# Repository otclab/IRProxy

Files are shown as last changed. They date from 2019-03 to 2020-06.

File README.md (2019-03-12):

# IRProxy

### Descripción del Proyecto

El proyecto surge de la necesidad de enviar señales de mando infrarrojas al decodificador  de cable, de manera de controlar su operación en forma remota desde donde no es posible  utilizar su propio control remoto infrarrojo.

La solución desarrollada es utilizar el conjunto _ESP8266_ y un microcontrolador <sup>(*1)</sup> de  manera obtener la capacidad de enviar los mandos desde una red inalámbrica (y por ende _LAN_ e  Internet inclusive), los cuales serían recibidos por el módulo _ESP8266_ y enviados por  medio del su puerto _SPI_ al microcontrolador, el cual se encargaría de generar la señal  infrarroja.

El microcontrolador se incluye porque en general el módulo _ESP8266_, no tiene la capacidad para generar un patrón infrarrojo arbitrario <sup>(*2)</sup> y porque la confiabilidad del microcontrolador es muy superior a la del módulo _ESP8266_ en cualquiera de los tres lenguajes que  se  usaron (_LUA_, _Arduino_/_++C_, y _(Micro)Python_), encargándose de cebar el sistema en caso  se pierda la comunicación por cualquier motivo.  

El protocolo de comunicación elegido es el **_MQTT_**, en razón que su soporte es mas estable y simple (contrario del _COAP_ o _HTTP_) en _NodeMCU_ <sup>(*3)</sup>. 

Por otro lado como frente _GUI_  en la _PC_ se  utiliza _Python_ con soporte de la librería _Kivy_, con la cual también se tiene mejor control  sobre el tamaño de la ventana de la aplicación y es menos exigente en cuanto recursos con  respecto a un navegador, con el agregado que facilita la compilación tanto para _Windows_ como  para _Android_ de manera de obtener aplicaciones para ambos SO.

La desventaja al utilizar el protocolo _MQTT_, es que debe utilizarse un servidor intermediario  (_Broker_), al contrario que en _Android_, por el lado de la _PC_ es un problema menor, para la  cual es fácil montar un servidor, sin embargo dado que el servidor _MQTT_ puede montarse en el  servidor _NAS_ como un servicio auxiliar que puede aprovecharse para otras aplicaciones _IoT_.

Con el fin de no restringir el proyecto a su objetivo inicial y también poder usarlo aún  es sus primeras etapas de desarrollo (con solo la captura de los patrones correspondientes a  las teclas mas frecuentes) sin realizar mayores cambios al adicionar nuevos patrones para  el mismo decodificador u otros equipos, se propone implementar el código del generador en  forma genérica, de manera que la estructura de tiempos del patrón es recibida cada vez  que deba emitirse.

 El libreto de _IPython_ _"Decodificacion de las Señales Infrarrojas del Control Remoto del  "Decodificador de Movistar.ipynb"_ se encarga de procesar la captura de las señales  infrarrojas realizadas con el osciloscopio _Rigol 1052E_, verifica la rectitud de la captura  y genera los archivos _XML_ de especificación de los patrones correspondientes, los  cuales pueden ser usados por la aplicación en _Python_ para la _PC_.

### Etapa Final 
 El diseño del equipo final incluye una fuente _DC/DC_ para compartir la alimentación del  decodificador, la cual proviene de un adaptador de _12VDC_, por lo que se incluye un  convertidor _DC/DC híbrido_ el cual consta de pre-regulador reductor conmutado, operando en lazo abierto seguido de un regulador lineal de 3.3V.  El microcontrolador auxiliar también se genera la señal de excitación del pre-regulador.
 
##### Notas
 
 >- <sup>(\*1)</sup>  Para la pruebas de concepto se utilizo el PIC16F1619, un sub-siguiente periodo de prueba se realizo con el PIC16F18313. En la etapa final para trabajo constante se utiliza también el PIC16F18313.
 >- <sup>(\*2)</sup>  La versión actual del SDK del ESP8266 tiene soporte para generación de señales infrarrojas aunque para un conjunto de formatos restringido, al momento no incluye el de Samsung.
 >- <sup>(\*3)</sup>  El módulo NodeMCU fue utilizado para las pruebas iniciales, programado en Lua resulto bastante inestable, en su lugar se utilizo para el periodo de prueba la versión de Arduino para el ESP8266, el cual fue bastante estable y requirió su reinicio pocas veces. Sin embargo después de la actualización del servidor NAS (a FreeNAS 11.0) perdió la capacidad de conectarse, por lo que se decidió utilizar Micropython como lenguaje de operación para el módulo.

### Patrón de Señales
  
Para conservar la capacidad de generar un patrón cualquiera su especificación se trasmite cada vez que deba generarse, ellas incluyen la frecuencia de la portadora, su ciclo de trabajo, seguido de la secuencia de tiempos de generación y pausa de los que consta.

El formato depende del medio donde se ejecuta el interprete _PC_, _ESP8266_ o _Microcontrolador_, para la aplicación de escritorio _IRProxy_PC.py_ se utiliza el formato _XML_, la especificación es embebida en la etiqueta **_IR_CODE_**, la cual contiene las etiquetas **_SOURCE_**, **_ID_**, **_CARRIER_**, y **_PATTERN_**.

La etiquetas **_SOURCE_** e **_ID_** sirven para identificar el equipo cuyas señales de control remoto infrarrojas y la tecla o función que emulan respectivamente.

<La etiqueta **_CARRIER_** incluye dos sub-etiquetas **_PERIOD_** y **_DUTY_CYCLE_**, en las que se definen los valores del periodo y ciclo de trabajo de la portadora, la unidad utilizada para estos se define por el atributo **_unit_** definido en la etiqueta **_CARRIER_**. Por conveniencia define la resolución del generador / temporizador utilizado para generarla (
<a href="https://www.codecogs.com/eqnedit.php?latex=\dpi{100}&space;\tiny&space;\frac{1}{32\,&space;MHZ}" target="_blank">\tiny \frac{1}{32\, MHZ}</a>
 para el PIC16F18313).

Dentro la etiqueta **_PATTERN_** se define la secuencia (_type="array"_) de pulsos, mediante la sub-etiquetas **_PULSE_**, las cuales a su vez constan de las etiquetas **_HIGH_** y **_LOW_**, que define los intervalos de activación y pausa de la portadora. Las unidades utilizadas se definen en el  atributo **_unit_**, como opción su valor puede ser _"CARRIER_PERIOD"_ implicando que las unidades  utilizadas para definir estos intervalos es el periodo de la portadora.

El formato para el envío del patrón hacia el módulo _ESP8266_, es una cadena de caracteres formada por la representación hexadecimal, de la secuencia de bytes que representan en forma consecutiva la _versión_, _número de pulsos_ el _periodo de la portadora_, su _ciclo de trabajo_, seguidos de los periodos de _activación_ y _pausa_ de cada pulso del patrón. 
En este caso no se trasmite la identificación del equipo y función a la que pertenece el patrón, pero se incluye la _versión del protocolo_, al momento solo existe la versión _1_ que es la descrita. Los valores de _127_  y _126_ se reservan para comunicación particular entre el módulo _ESP8266_ y el _microcontrolador_.

La secuencia de bytes de cada valor es la correspondiente a la codificación _VLQ_ (_Variable Length Quantity_), que utiliza el valor del bit de mayor peso de cada byte para indicar si es el último, es decir si la representación en base $128$ del valor es $A_n ...  A_1 A_0$, la secuencia utilizada es <span lang="latex">(A_0+128), (A_1+128), ... (A_n + 0)</span>. 

Nótese que los valores de los tiempos deben estar especificados en la unidad de tiempo utilizada por el microcontrolador.

Finalmente, el formato de envío al microcontrolador es la secuencia de bytes antes descrita ( no su representación hexadecimal).  Los valores reservados para la versión son utilizados para :
>- _0xFF_ : Informar que la comunicación es correcta (_keepalive_).
>- _0xFE_ : Solicitud de cebado del sistema (_reset_).

####  Limitaciones del Patrón de Señales
Desde el punto de vista de la arquitectura de la especificación y su serialización, no existe limitación, sin embargo la implementación de la generación en el _microcontrolador_ impone algunas :
  >- El campo del número de pulsos esta limitado a 255. En la practica el número de pulsos esta limitado por el almacenamiento reservado al patrón, en la versión actual 46 bytes.
  >- Los periodos de tiempo se limitan a 65535 de las unidades respectivas.

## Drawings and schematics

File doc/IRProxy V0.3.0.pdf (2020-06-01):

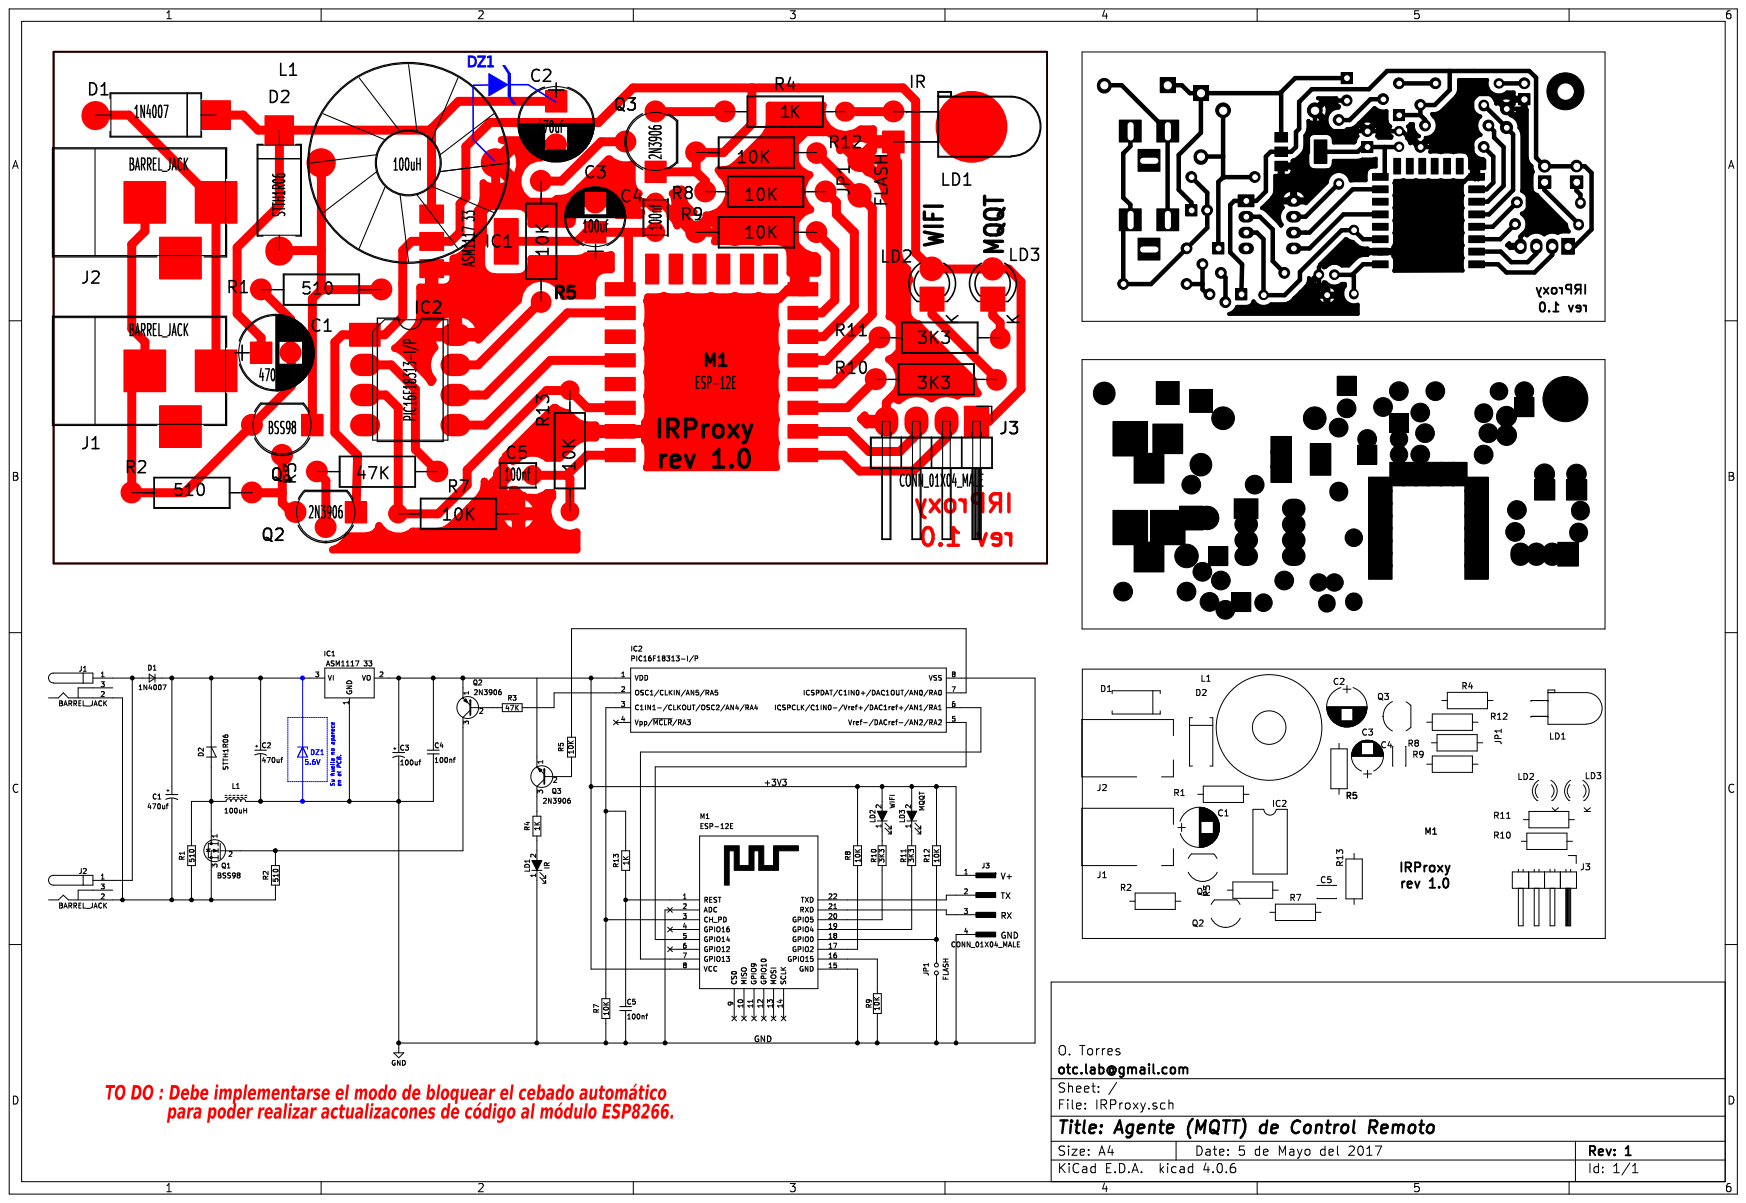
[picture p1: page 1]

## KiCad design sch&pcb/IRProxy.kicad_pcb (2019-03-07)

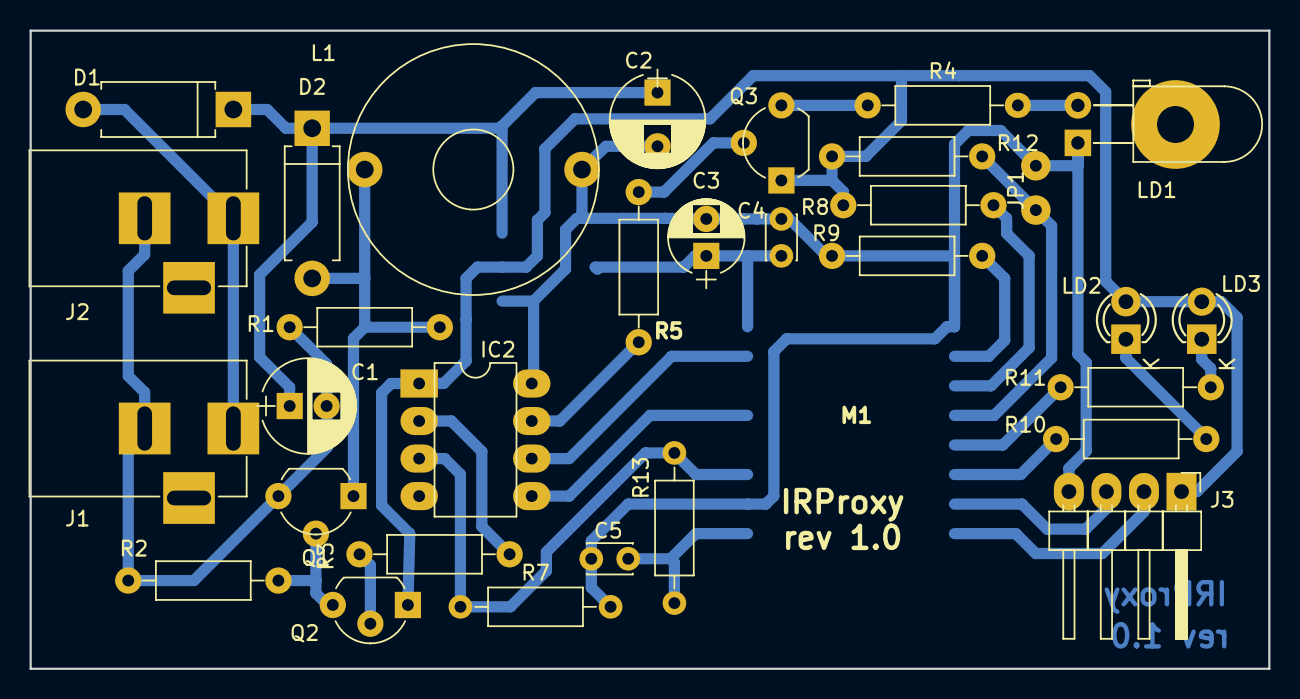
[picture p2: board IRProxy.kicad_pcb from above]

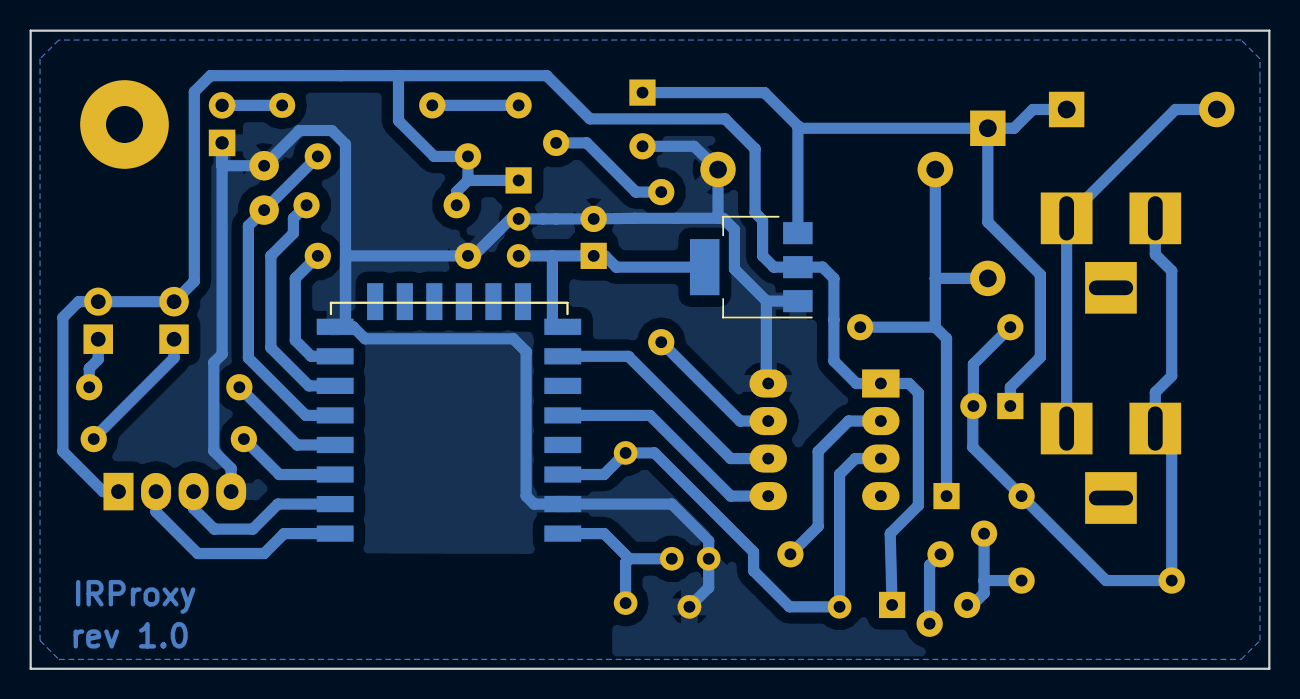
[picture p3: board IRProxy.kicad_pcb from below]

Board: 2 copper layers, 83.8 x 43.2 mm, 33 parts (2 on the bottom side), 26 nets.

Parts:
C1, C2: 470uf; CP_Radial_D6.3mm_P2.50mm
C3: 100uf; CP_Radial_D5.0mm_P2.50mm
C4, C5: 100nf; C_Disc_D3.0mm_W2.0mm_P2.50mm
D1: 1N4007; D_DO-15_P10.16mm_Horizontal
D2: STTH1R06; D_DO-15_P10.16mm_Horizontal
IC1: ASM1117 33; SOT-223
IC2: PIC16F18313-I/P; DIP-8_W7.62mm
J1, J2: BARREL_JACK
J3: CONN_01X04_MALE; Pin_Header_Angled_1x04_Pitch2.54mm
JP1: FLASH; WireConnection_0.80mmDrill
L1: 100uH; L_Toroid_Horizontal_D16.8mm_P14.70mm_Vishay_TJ3
LD1: IR; LED_D5.0mm_Horizontal_O3.81mm_Z15.0mm
LD2: WIFI; LED-3MM
LD3: MQQT; LED-3MM
M1: ESP-12E; ESP-12E_SMD
Q1: BSS98; TO-92_Molded_Wide
Q2, Q3: 2N3906; TO-92_Molded_Wide
R1, R2: 510; R_Axial_DIN0207_L6.3mm_D2.5mm_P10.16mm_Horizontal
R3: 47K; R_Axial_DIN0207_L6.3mm_D2.5mm_P10.16mm_Horizontal
R4, R13: 1K; R_Axial_DIN0207_L6.3mm_D2.5mm_P10.16mm_Horizontal
R5, R7, R8, R9, R12: 10K; R_Axial_DIN0207_L6.3mm_D2.5mm_P10.16mm_Horizontal
R10, R11: 3K3; R_Axial_DIN0207_L6.3mm_D2.5mm_P10.16mm_Horizontal

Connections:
/+3V3: C3.1, C4.1, IC1.2, IC2.1, J3.1, LD2.2, LD3.2, M1.8, Q2.1, R8.1, R12.1
GND: C2.2, C3.2, C4.2, C5.2, IC1.1, IC2.8, J3.4, JP1.2, L1.2, LD1.1, M1.2, M1.15, R7.2, R9.1
unnamed: C1.1, C2.1, D1.1, D2.1, IC1.3
unnamed: C1.2, J1.2, J2.2, Q1.3, R1.2, R2.2
unnamed: C5.1, M1.1, R13.2
unnamed: D1.2, J1.1, J2.1
unnamed: D2.2, L1.1, Q1.1, R1.1
unnamed: IC2.2, R3.1
unnamed: IC2.3, M1.3, R7.1, R13.1
unnamed: IC2.5, M1.5
unnamed: IC2.6, M1.7
unnamed: IC2.7, R5.2
unnamed: J3.2, M1.22
unnamed: J3.3, M1.21
unnamed: JP1.1, M1.18, R12.2
unnamed: LD1.2, R4.2
unnamed: LD2.1, R10.2
unnamed: LD3.1, R11.2
unnamed: M1.16, R9.2
unnamed: M1.17, R8.2
unnamed: M1.19, R11.1
unnamed: M1.20, R10.1
unnamed: Q1.2, Q2.3, R2.1
unnamed: Q2.2, R3.2
unnamed: Q3.2, R5.1
unnamed: Q3.3, R4.1

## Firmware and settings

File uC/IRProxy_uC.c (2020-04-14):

 /* IRProxy.c
 *

 Descripción del Proyecto
 ~~~~~~~~~~~~~~~~~~~~~~~~

 El proyecto surge de la necesidad de enviar señales de mando infrarrojas al decodificador
 de cable, de manera de controlar su operación en forma remota desde donde no es posible
 utilizar su propio control remoto infrarrojo.

 La solución desarrollada es utilizar el conjunto ESP8266 y un microcontrolador (*1) de
 manera obtener la capacidad de enviar los mandos desde una red wifi (y por ende LAN e
 Internet inclusive), los cuales serían recibidos por el módulo ESP8266 y enviados por
 medio del puerto SPI al microcontrolador, el cual se encargaría de generar la señal
 infrarroja.

 El microcontrolador se incluye porque en general el módulo ESP8266, no tiene la capacidad
 para generar un patrón infrarrojo arbitrario(*2). Otras de las funciones del microcontrolador
 es la capacidad de cebar el ESP8266 de ser necesario.

 El protocolo de comunicación elegido es el MQTT, en razón que su soporte es mas estable y
 simple (contrario del COAP o HTTP) en NodeMCU (*3). Por otro lado como frente al usuario se
 utiliza Python con soporte de la librería Kivy, con la cual también se tiene mejor control
 sobre el tamaño de la ventana de la aplicación y es menos exigente en cuanto recursos con
 respecto a un navegador, con el agregado que facilita la compilación tanto para Windows como
 para Android de manera de obtener aplicaciones para ambos SO.

 La desventaja al utilizar el protocolo MQTT, es que debe utilizarse un servidor intermediario
 (Broker), al contrario que en Android, por el lado de la PC es un problema menor, para la
 cual es fácil montar un servidor, sin embargo dado que el servidor MQTT puede montarse en el
 servidor NAS como un servicio auxiliar, puede aprovecharse para otras aplicaciones IoT.

 Con el fin de no restringir el proyecto a su objetivo inicial y también poder usarlo aún
 es sus primeras etapas de desarrollo (con solo la captura de los patrones correspondientes a
 las teclas mas frecuentes) sin realizar mayores cambios al adicionar nuevos patrones para
 el mismo decodificador u otros equipos, se propone implementar el código del generador en
 forma genérica, de manera que la estructura de tiempos del patrón es recibida cada vez
 que deba emitirse.

 El libreto de IPython "Decodificacion de las Señales Infrarrojas del Control Remoto del
 Decodificador de Movistar.ipynb" se encarga de procesar la captura de las señales
 infrarrojas realizadas con el osciloscopio Rigol 1052E, verifica la rectitud de la captura
 y genera los archivos XML de especificación de los patrones correspondientes, los
 cuales pueden ser usados por la aplicación en Python

 Etapa Final 
 ~~~~~~~~~~~
 
 El diseño del equipo final incluye una fuente DC/DC para compartir la alimentación del 
 decodificador, la cual proviene de un adaptador de 12VDC, por lo que se incluye un 
 convertidor DC/DC híbrido el cual consta de pre-regulador conmutado step-down, operando en
 lazo abierto seguido de un regulador líneal de 3.3V. Por lo que se incluye en el codigo 
 la generación de la señal PWM con el soporte del NCO.
 
 También se incluye el código el supervisor del módulo ESP8266, para re-inicializar el 
 sistema si la comunicacíon (inter microcontrolador-módulo, router y/o servidor MQTT) se
 corta.
 
 Se pone en operación el 27 de Junio del 2017
 
 
 Notas
 ~~~~~

 (*1) : Para la pruebas de concepto se utilizo el PIC16F1619, un sub-siguiente periodo de
        prueba se realizo con el PIC16F18313. En etapa final para trabajo constante se
        utiliza también el PIC16F18313.

 (*2) : La versión actual del SDK del ESP8266 tiene soporte para generación de señales
        infrarojas aunque para un conjunto de formatos restringido, al momento no incluye
        el de Samsung.

 (3*) : El módulo NodeMCU fue utilizado para las pruebas iniciales, programado en Lua
        resulto bastante inestable, en su lugar se utilizo para el periodo de prueba
        la versión de Arduino para el ESP8266, el cual fue bastante estable y requirio
        su reinicio pocas veces.
*/


/* Patrón de Señales Infrarojas
 * ~~~~~~~~~~~~~~~~~~~~~~~~~~~~
 * 
 * El patrón se recibe como una secuencia de números de longitud variable, de la cual la
 * interpretación de los 3 primeros números es la siguiente :
 *  [Versión de Protocolo]
 *  [Número de Pulsos (de la envolvente) del patrón].
 *  [Periodo de la Portadora, en ciclos del Oscilador del microcontrolador (32 MHz)] :
 *  [Periodo Activo de los Ciclos de la Portadora, en las mismas unidades]
 *
 * Los siguientes números definen en forma secuencial, para cada pulso del patrón la
 * duración en ciclos de la portadora :
 *  [Duración de la parte activa de la portadora]
 *  [Duración de la ausencia de portadora]
 *
 * La Versión del Protocolo, es 0x01 para el mando de control infrarrojo.
 *
 * Los números son codificados de la siguiente manera, se N el valor numérico :
 *    N <= 127           : 1 Byte, con el valor del Número N
 *    0x3FFF >= N >= 128 : 2 Bytes, byte LSB = 0x80 + (N % 128)
 *                                  byte MSB = int(N/128)
 *
 * Después del inicio, se espera por la recepción de la temporización (completa) del
 * patrón a generar y luego se procede a generarlo.
 *
 * La recepción de la temporización de un patrón es ignorada, mientras su emisión esta
 * en curso.
 *
 * La recepción de la temporización con un formato incorrecto, incompleto o sin respetar
 * el límite de tiempo intercaracteres también es ignorada y además en este caso se espera 
 * hasta que la transmisión cese por al menos el tiempo CLEARANCE_TIME antes de ser 
 * aceptada nuevamente.
 *
 * 
 * Otros Protocolos
 * ~~~~~~~~~~~~~~~~
 * 
 * La versión del protocolo acepta los siguientes valores para la identificación del 
 * protocolo :
 *    0x7F : Mensaje de verificación de la conexión microconrolador-módulo (KEEPALIVE_ID).
 *    0x7E : Mensaje de solicitud de cebado (RESETREQ_ID).
 * 
 * En ambos casos deben ser eguidos por un byte con el valor 0x00 (i.e. sin carga/payload).
*/

#if __16F18313
  // PIC16F18313 Configuration Bit Settings
  // 'C' source line config statements

  // CONFIG1
  #pragma config FEXTOSC = OFF    // FEXTOSC External Oscillator mode Selection bits (Oscillator not enabled)
  #pragma config RSTOSC = HFINT32 // Power-up default value for COSC bits (HFINTOSC with 2x PLL (32MHz))
  #pragma config CLKOUTEN = OFF   // Clock Out Enable bit (CLKOUT function is disabled; I/O or oscillator function on OSC2)
  #pragma config CSWEN = ON       // Clock Switch Enable bit (Writing to NOSC and NDIV is allowed)
  #pragma config FCMEN = OFF      // Fail-Safe Clock Monitor Enable (Fail-Safe Clock Monitor is disabled)

  // CONFIG2
  #pragma config MCLRE = OFF      // Master Clear Enable bit (MCLR/VPP pin function is MCLR; Weak pull-up enabled )
  #pragma config PWRTE = ON       // Power-up Timer Enable bit (PWRT disabled)
  #pragma config WDTE = OFF       // Watchdog Timer Enable bits (WDT enabled, SWDTEN is ignored)
  #pragma config LPBOREN = OFF    // Low-power BOR enable bit (ULPBOR disabled)
  #pragma config BOREN = OFF      // Brown-out Reset Enable bits (Brown-out Reset enabled, SBOREN bit ignored)
  #pragma config BORV = LOW       // Brown-out Reset Voltage selection bit (Brown-out voltage (Vbor) set to 2.45V)
  #pragma config PPS1WAY = OFF    // PPSLOCK bit One-Way Set Enable bit (The PPSLOCK bit can be set and cleared repeatedly (subject to the unlock sequence))
  #pragma config STVREN = ON      // Stack Overflow/Underflow Reset Enable bit (Stack Overflow or Underflow will cause a Reset)
  #pragma config DEBUG = OFF      // Debugger enable bit (Background debugger disabled)

  // CONFIG3
  #pragma config WRT = OFF        // User NVM self-write protection bits (Write protection off)
  #pragma config LVP = OFF        // Low Voltage Programming Enable bit (HV on MCLR/VPP must be used for programming.)

  // CONFIG4
  #pragma config CP = OFF         // User NVM Program Memory Code Protection bit (User NVM code protection disabled)
  #pragma config CPD = OFF        // Data NVM Memory Code Protection bit (Data NVM code protection disabled)


#elif __16F1619
  // PIC16F1619 Configuration Bit Settings
  // 'C' source line config statements

  // CONFIG1
  #pragma config FOSC = INTOSC    // Oscillator Selection Bits (INTOSC oscillator: I/O function on CLKIN pin)
  #pragma config PWRTE = OFF      // Power-up Timer Enable (PWRT disabled)
  #pragma config MCLRE = OFF      // MCLR Pin Function Select (MCLR/VPP pin function is digital input)
  #pragma config CP = OFF         // Flash Program Memory Code Protection (Program memory code protection is disabled)
  #pragma config BOREN = OFF      // Brown-out Reset Enable (Brown-out Reset disabled)
  #pragma config CLKOUTEN = OFF   // Clock Out Enable (CLKOUT function is disabled. I/O or oscillator function on the CLKOUT pin)
  #pragma config IESO = ON        // Internal/External Switch Over (Internal External Switch Over mode is enabled)
  #pragma config FCMEN = ON       // Fail-Safe Clock Monitor Enable (Fail-Safe Clock Monitor is enabled)

  // CONFIG2
  #pragma config WRT = OFF        // Flash Memory Self-Write Protection (Write protection off)
  #pragma config PPS1WAY = ON     // Peripheral Pin Select one-way control (The PPSLOCK bit cannot be cleared once it is set by software)
  #pragma config ZCD = OFF        // Zero Cross Detect Disable Bit (ZCD disable.  ZCD can be enabled by setting the ZCDSEN bit of ZCDCON)
  #pragma config PLLEN = ON       // PLL Enable Bit (4x PLL is always enabled)
  #pragma config STVREN = ON      // Stack Overflow/Underflow Reset Enable (Stack Overflow or Underflow will cause a Reset)
  #pragma config BORV = LO        // Brown-out Reset Voltage Selection (Brown-out Reset Voltage (Vbor), low trip point selected.)
  #pragma config LPBOR = OFF      // Low-Power Brown Out Reset (Low-Power BOR is disabled)
  #pragma config LVP = ON         // Low-Voltage Programming Enable (Low-voltage programming enabled)

  // CONFIG3
  #pragma config WDTCPS = WDTCPS1F// WDT Period Select (Software Control (WDTPS))
  #pragma config WDTE = OFF       // Watchdog Timer Enable (WDT disabled)
  #pragma config WDTCWS = WDTCWSSW// WDT Window Select (Software WDT window size control (WDTWS bits))
  #pragma config WDTCCS = SWC     // WDT Input Clock Selector (Software control, controlled by WDTCS bits)

  // #pragma config statements should precede project file includes.
  // Use project enums instead of #define for ON and OFF.
#endif


/* Referencias Externas :
*/
#include <xc.h>
#include <stdint.h>
#include <stdbool.h>


/* Oscilador(es) del microcontrolador :
*/
#define FINTRC                  (32E6)
#define FOSC                    FINTRC
#define FCY                     (FINTRC/4)
#define LFINTOSC                (31e3)


/* Asignación de E/S :
*/
// Excitación PWM del Pre-Regulador :
#define TRIS_SD_PWM             TRISAbits.TRISA5
#define ANSEL_SD_PWM            ANSELAbits.ANSA5
#define LAT_SD_PWM              LATAbits.LATA5
#define PPS_NCOOUT             (0b11101)
#define SD_PWM_PPS              RA5PPS

// Excitación PWM de LED Infrarojo :
#define TRIS_IR_PWM             TRISAbits.TRISA0
#define ANSEL_IR_PWM            ANSELAbits.ANSA0
#define LAT_IR_PWM              LATAbits.LATA0
#define PPS_CCP1OUT             (0b01100)
#define IR_PWM_PPS              RA0PPS

// Interfaz SPI (solo SCK y SDI) :
#define TRIS_SDI                TRISAbits.TRISA1
#define ANSEL_SDI               ANSELAbits.ANSA1
#define PPS_SDI                 (0b00001)           /* RA1 */

#define TRIS_SCK                TRISAbits.TRISA2
#define ANSEL_SCK               ANSELAbits.ANSA2
#define PPS_SCK                 (0b00010)           /* RA2 */

// Señal de cebado (RESET) del Módulo ESP8266 :
#define TRIS_ESP8266_RST        TRISAbits.TRISA4
#define ANSEL_ESP8266_RST       ANSELAbits.ANSA4
#define LAT_ESP8266_RST         LATAbits.LATA4

#if __16F1619 
  #undef ANSEL_SD_PWM
  uint8_t fake_ansel ;
  #define ANSEL_SD_PWM          fake_ansel
#endif

  
/* Complemento de Tipos estándar :
*/
//typedef unsigned short long   uint24_t ;



/* Prototipos :
*/


/** Base de Tiempos ********************************************************************/

/* TICK_PERIOD es la unidad de tiempo utilizada para medir el tiempo en la secuencia de 
 * arranque y actividad del Módulo ESP8266 :
*/
#define TICK_CLK                    (LFINTOSC/16)     /* Hz.  */
#define TICK_PERIOD                 (0.1)             /* seg. */

/* Contador de tiempo (ticks) :
*/
int16_t tick_cnt ;

#if __16F18313
  void Tick_init(void) {
    T0CON1bits.T0CS    = 0b100  ; // Reloj derivado de LFINTOSC (32KHZ).
    T0CON1bits.T0CKPS  = 0b0100 ; // Taza del Pre-divisor = 1:16
    T0CON0bits.T0OUTPS = 0b0000 ; // Taza del Post-divisor = 1:1
    T0CON0bits.T016BIT = 0      ; // Modo del Temporizador en 8 bits.

    TMR0L = 0  ;
    TMR0H = (uint8_t)(TICK_PERIOD * TICK_CLK) ;
    PIR0bits.TMR0IF = 0 ;
    PIE0bits.TMR0IE = 0 ;
    T0CON0bits.T0EN = 1 ; // Enciende el temporizador TMR0

    tick_cnt = 0 ;
  }


  void Tick_task(void) {
    if (PIR0bits.TMR0IF) {
      PIR0bits.TMR0IF = 0 ;
      ++tick_cnt ;
      asm("CLRWDT") ;
    }
  }

#elif __16F1619
  void Tick_init(void) {
    T6HLTbits.MODE  = 0b000  ; // Modo estándar.    
    T6CLKCONbits.CS = 0b0011 ; // Reloj derivado de LFINTOSC (32KHZ).
    T6CONbits.CKPS  = 0b0100 ; // Taza del Pre-divisor = 1:16
    T6CONbits.OUTPS = 0b0000 ; // Taza del Post-divisor = 1:1
    
    TMR6 = 0  ;
    PR6  = (uint8_t)(TICK_PERIOD * TICK_CLK) ;
    PIR2bits.TMR6IF = 0 ;
    PIE2bits.TMR6IE = 0 ;
    
    T6CONbits.ON = 1 ; // Enciende el temporizador TMR6

    tick_cnt = 0 ;
  }


  void Tick_task(void) {
    if (PIR2bits.TMR6IF) {
      PIR2bits.TMR6IF = 0 ;
      ++tick_cnt ;
      asm("CLRWDT") ;
    }
  }
#endif
  
/** Pre-Regulador de Tensión ***********************************************************/
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
void main(void) {
enum {
  STARTUP_EXTENDED_DELAY_STAGE ,
  PS_STARTUP_DELAY_STAGE       ,
  PS_STARTUP_STAGE             ,
  EPS_STARTUP_DELAY_STAGE       ,
  EPS_STARTUP_STAGE             ,  
  PROXY_STAGE
} stage ;
uint8_t n, b ;

  /* Inicialización del sistema interno del microcontrolador :
  */
  #if __16F18313
    // Oscilador : FOSC = 32 MHz, FCY = 8 MHz, TCY = 0.125 uS.
    OSCCON1bits.NOSC   = 0b000 ; OSCCON1bits.NDIV = 0b0000 ;
    OSCCON3bits.SOSCBE = 0 ;

    // Prepara las E/S como salidas a su estado inactivo por defecto :
    // (particularmente mantiene cebado al módulo ESP8266 y en el modo
    // de bajo consumo, indispensable para el arranque del sistema en
    // cuanto el pre-regulador de tensión esta todavía apagado.)
    LATA = 0x21 ; TRISA = 0xCE ; ANSELA = 0 ; INLVLA = 0 ;

    // Define el periodo del guardián del microcontrolador :
    WDTCONbits.WDTPS   = 0b01110 ; // 16 seg.
    WDTCONbits.SWDTEN  = 0       ; // Guardián encendido.
  #elif __16F1619
    OSCCONbits.SCS    = 0b00   ; // Oscilador Primario (i.e. HFINTOSC).
    OSCCONbits.IRCF   = 0b1110 ; // Oscilador interno (HFINTOSC) a 8 MHz.
    OSCCONbits.SPLLEN = 1      ; // Multiplidcador PLL activo.      

    // Define el periodo del guardián del microcontrolador :
    OPTION_REG = 0x8F ;
    WDTCON0bits.WDTPS  = 0b01110 ; // 16 seg.
    WDTCON1bits.WDTCS  = 0b000   ; // Reloj derivado del LFINTOSC
    WDTCON1bits.WINDOW = 0b111   ; // Sin Ventana.

    WDTCON0bits.SEN   = 1        ; // Guardián Apagado.
#endif

  // Como una medida para no saturar el medio con solicitudes de conexión, en forma
  // continua, se evalua el número de re-intentos de cebado, para decidir si permite 
  // el arranque del móculo ESP8266 en forma inmediata (NORMAL_DELAY_TIME seg.) o se
  // difiere por un tiempo prudente (EXTENDED_DELAY_TIME) :
  if ((reset_retries.validation_key == RETRIES_VALID_KEY) 
                                         && (reset_retries.cnt > MAX_RETRIES_REQUEST)) {
    stage = STARTUP_EXTENDED_DELAY_STAGE ;
    stage = PS_STARTUP_DELAY_STAGE ;
  }
  else {
    stage = PS_STARTUP_DELAY_STAGE ;
  }

  // Se asegura que la clave de validación del arranque sea válida en los subsiguientes
  // arranques en caliente :
  if (reset_retries.validation_key != RETRIES_VALID_KEY) {
    reset_retries.validation_key = RETRIES_VALID_KEY ;
    reset_retries.cnt = 0 ;
  }

  // Configura el pre-regulador :
  SDPWM_init() ;

  // Arranca la base de tiempos :
  Tick_init() ;

  // Finalmente, activa las interrupciones y arranca el sistema :
  INTCONbits.GIE  = 1 ; INTCONbits.PEIE = 1 ;

  // e inicia las tareas ...
  while (1) {
    switch (stage) {
      case STARTUP_EXTENDED_DELAY_STAGE :
        if (tick_cnt > (int16_t)(EXTENDED_DELAY_TIME/TICK_PERIOD)) {
          stage = PS_STARTUP_STAGE ;
          tick_cnt = 0 ;
        }

        // Durante esta etapa solo la tarea de control de tiempo esta activa :
        Tick_task() ;
      break ;
      
      case PS_STARTUP_DELAY_STAGE :
        //if (tick_cnt > (uint16_t)(NORMAL_DELAY_TIME/TICK_PERIOD)) stage = STARTUP_STAGE ;
        if (tick_cnt > 10) {
          stage = PS_STARTUP_STAGE ;
          tick_cnt = 0 ;
        }
        
        // Durante esta etapa solo la tarea de control de tiempo esta activa :
        Tick_task() ;
      break ;

      case PS_STARTUP_STAGE :
        // Arranca el Pre-regulador :
        SDPWM_start() ;

        stage = EPS_STARTUP_DELAY_STAGE ;
        tick_cnt = 0 ;

        Tick_task() ;
      break ;

      case EPS_STARTUP_DELAY_STAGE :
        //if (tick_cnt > (uint16_t)(NORMAL_DELAY_TIME/TICK_PERIOD)) stage = STARTUP_STAGE ;
        if (tick_cnt > 10) {
          stage = EPS_STARTUP_STAGE ;
          tick_cnt = 0 ;
        }
        
        // Durante esta etapa solo la tarea de control de tiempo esta activa :
        Tick_task() ;
      break ;

      case EPS_STARTUP_STAGE :
        // Configura el temporizador del guardián del módulo ESP8266 :
        ESP8266Watchdog_init() ;

        // Configura el generador IR ...
        IRCodeInit() ;

        // y el receptor de códigos :
        PatternRcveInit() ;

        stage = PROXY_STAGE ;

        Tick_task() ;
      break ;

      case PROXY_STAGE :
        // Se recibe el patrón :
        if (PatternRcveTask()) {
          // Se recibió un mensaje y se procesa de acuerdo a su tipo :
          switch (irCodeRX[0]) {
            case INFRARED_REMOTE_PROXY_PROTOCOL :
              // Trasmite la señal respectiva al código recibido :
              IRCodeXmit() ;
              
              // Puesta a cero del Guardián del módulo ESP8266 :
              ESP8266Watchdog_rearm(IR_INACTIVITY_TIMER) ;
              
              // Cancela el cebado largo, si es necesario :
              reset_retries.cnt = 0 ;
            break ;

            case KEEPALIVE_ID :
              // Se recibó el mensaje de confirmación que comunicacíon esta operativa,
              // se realiza la puesta a cero del guardián del módulo ESP8266 :
              ESP8266Watchdog_rearm(KEEPALIVE_TIMER) ;
            break ;

            case RESETREQ_ID :
              // El módulo solicita su cebado (no pudo establecer comunicación con el router
              // o el servidor MQQT), en consecuencia se ceba el sistema :
              ESP8266Watchdog_reset() ;
          }

          // Se continua con la recepción del siguiente mensaje :
        }
        else {
          // Se recibio un mensaje con un formato incorrecto :
          PatternRcveClearance() ;
        }
      break ;

      default :
        asm("RESET") ;
    }
  }
}

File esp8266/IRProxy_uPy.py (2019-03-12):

#!python
# -*- coding: utf-8 -*-

# ir_proxy_py.py
# Version 0.3.0

import utime
import network
from machine import Pin, SPI
from umqtt.simple import MQTTClient
from secrets import *
  

RESET_REQ_CODE   = b'\x7E\x00'
KEEPALIVE_CODE   = b'\x7F\x00'

# Se debe enviar el código guardián (KEEPALIVE_CODE), antes que transcurra el periodo especificado
# (KEEPALIVE_PERIOD), desde la última transmisión , se utiliza keepalive_cnt para medir este tiempo :
KEEPALIVE_PERIOD = 120 # en unidades de 0.1 seg.
keepalive_cnt = 0

# Intervalos de espera para reintentar la conexión con el router. Debe terminar en 0 pues no tiene
# caso esperar después del último (re-)intento, define implícitamente el número de reintentos (ie.
# (len(wifi_timeout)-1) : 
wifi_timeout = (2, 2, 5, 20, 30, 0)

# SSID del Router
ssid = WIFI_SSID
password = WIFI_PSW

# IP y puerto del broker MQTT (estándar para comunicación no cifrada}) :
broker_ip = MQTT_BROKER
port = MQTT_PORT

# ID del cliente y tópico al que se suscribe :
client_id_header = 'IR_PROXY_uPython_'
topic = b'ir_proxy/deco_tv'

# Se definen las líneas de control de los LEDs:
led_broker_OK = Pin(5, Pin.OUT)
led_wifi_OK = Pin(4, Pin.OUT)
# Se define el contador de señalización de mensajes del broker :
broker_cnt = 0

# inicialmente los LEDs se apagan, nótese que el estado de los LEDs es complementario a del
# los pines de control :
led_broker_OK.on()
led_wifi_OK.on()

# Arranque del interfaz SPI (hardware):
# CPOL = 0 ; CPHA = 0
hspi = SPI(1, baudrate=1000000, polarity=0, phase=0)
data = bytearray(50)

def show_APs() :
  for n, ap in enumerate(network.WLAN(network.STA_IF).scan()) :
    print(' {:d}: {:s} [{:d}dbm] CH{:2d} {:12s} {:s}'.format(n, ap[0], ap[3], ap[2],
     ('Abierta', 'WEP', 'WPA-PSK', 'WPA2-PSK', 'WPA/WPA2-PSK')[ap[4]], ('Visible', 'Oculta')[ap[5]]))
  print('\n')


def client_task(client) :
  global broker_cnt

  # Verifica si existen mensajes recibidos :
  client.check_msg()

  # Se apaga temporalmente el led de broker para indicar que se recibió un mensaje :
  if broker_cnt > 0 :
    led_broker_OK.on()
    broker_cnt -= 1
    
  else :
    # TO DO : Mecanismo de verificación que la conexión con el broker esta activa.
    led_broker_OK.off()


# Se conecta a la red seleccionada, espera hasta un máximo de 20 seg. por la confirmación,
# luego devuelve True/False según este conectada o no.
def wifi_connect() :
  # Se prepara para configurar la conexión como estación :
  sta_if = network.WLAN(network.STA_IF)
  sta_if.active(True)

  if (sta_if.config('essid') != ssid) or  (not sta_if.isconnected()) :
    print('Seleccionando la red {:s}'.format(ssid))
    sta_if.connect(ssid, password)
    led_wifi_OK.on()

  for n in range(40) :
    if sta_if.isconnected() : break
    utime.sleep_ms(500)
  else :
    print('No se pudo conectar a {:s}.'.format(ssid)) 
    print('Las redes reconocibles son :')
    show_APs()
    
    return False

  led_wifi_OK.off()
  print('Red Wifi         : {:s}'.format(sta_if.config('essid')))
  print('Dirección MAC    : {:02X}:{:02X}:{:02X}:{:02X}:{:02X}:{:02X}'.format(*sta_if.config('mac')))
  print('Dirección IP     : {:s}\nMáscara          : {:s}\nPuerta de Enlace : {:s}\nDNS              : {:s}'.format(*sta_if.ifconfig()))

  return True

  
# Función de callback para el proceso de los mensajes al tópico suscrito. Decodifica el mensaje
# para convertirlo en la secuencia de bytes que representa.
def relay_code(topic, code_str) :
  global keepalive_cnt, broker_cnt

  def print_msg(msg) : print('Mensaje recibido : {:s}'.format(code_str))

  if len(code_str) % 2 == 0 :
    try :
      print('decoding ...')
      data = bytearray(int(chr(h1)+chr(h2), 16) for h1,h2 in zip(*[iter(code_str)]*2))
    except Exception as e :
      print('El mensaje recibido contiene caracteres diferentes de las cifras hexadecimales.')
      print_msg(code_str)
      print('Excepción : {!r}'.format(e))
      return

    print('Re-dirigiendo el mensaje al puerto SPI.')
    print_msg(code_str)
    print('packed_data : {!r}'.format(data))
    hspi.write(data)
    print('Done\n\n')
    
    # Se señaliza la recepción (como consecuencia se apaga el LED del broker brevemente) :
    broker_cnt = 1
    
    # Finalmente se reinicia el periodo de espera del guardián :
    keepalive_cnt = 0

  else :
    # El mensaje no tiene la longitud correcta :
    print('El mensaje recibido no tiene una longitud par.\n')
    print_msg(code_str)

    
# task
def task() :
  global keepalive_cnt, wifi_timeout, broker_ip, topic

  while 1 :
    num_retries = 5
    # Intenta recuperar la conexión Wifi :
    for timeout in wifi_timeout:
      if wifi_connect() : break 
      # Se aumenta progresivamente el tiempo de espera para el siguiente intento :
      utime.sleep(timeout)
    else :
      # No se pudo conectar a la red DELFOS. Se termina el proceso, para que a continuación
      # se solicite el cebado del sistema ...
      break

    # Intenta conectarse con el servidor MQTT :
    num_retries = 5
    for n in range(num_retries) :
      try :
        print('[{:d}/{:d}] Conectándose al Servidor MQTT : {:s} ... '.format(n+1, num_retries, broker_ip), end='')
        
        # Nótese que el ID del cliente debe diferente a otros, al menos en redes locales una forma
        # de asegurar su singularidad es agregar el IP :
        client = MQTTClient(client_id_header + network.WLAN(network.STA_IF).ifconfig()[0], broker_ip)
        client.set_callback(relay_code)

        # Inicia la conexión con el broker :
        client.connect()

        print('conectado!')
        break
      except Exception as e:
        print('no resulto!')
        print('Razón : ', e)
        
        # Se re-intenta ... 
        utime.sleep(2)
        continue
    else :
      # No se pudo conectar a con el servidor MQTT. Se termina el proceso, para que a continuación
      # se solicite el cebado del sistema ...
      break

    # Se suscribe al tópico :
    num_retries = 5
    for n in range(num_retries) :
      try :
        print('[{:d}/{:d}] Suscribiéndose al Tópico <<{:s}>> ... '.format(n+1, num_retries, topic), end='')
        print 
        client.subscribe(topic)
        print('suscrito!')
        break 
        
      except Exception as e:
        print('no resulto!')
        print('Razón : ', e)
                
        # Se re-intenta :
        utime.sleep(2)
        continue
    else :
      # No se pudo suscribir en el tópico. Se termina el proceso, para que a continuación
      # se solicite el cebado del sistema ...
      break

    # Se continúa con la re-trasmisión de los códigos/patrones recibidos :
    keepalive_cnt = 0
    try :
      while network.WLAN(network.STA_IF).isconnected() :
        client_task(client)
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

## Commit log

2019-03-07 IRProxy basada en MycroPython
    Importación inicial del repetidor de señales de control remoto infrarrojo : IRProxy
    [IRProxy.kicad_pcb, IRProxy.sch]
2019-03-10 Refina la secuencia de encendido del módulo ESP8266
    Se incluye un retardo entre el encendido del módulo y el de la fuente DC/DC del pre-regulador.
2019-03-10 Corrige la presentación de las redes disponibles.
    [IRProxy_uPy.py]
2019-03-10 Se modifica el nombre simbólico del Broker.
    [IRProxy_uPy.py]
2019-03-10 Se actualiza el nombre del modulo de la aplicación en main.py
2019-03-10 Actualizando la portada, README.md
2019-03-12 Se repara la falta de parpadeo del LED de conexión al broker al recibir un mensaje.
    [IRProxy_uPy.py]
2020-04-14 Fija la posición por defecto.
    Se define la posición de arranque, para ubicarse justo sobre la ventana PIP.
2020-04-14 Reajuste de la tensión de entrada del pre-regulador.
    Se prepara el pre-regulador para una entrada de 12V,.
2020-05-26 Flow para Node-Red
    Se añade el flujo para Node-Red, que implementa un interfaz UI para navegadores., particularmente desde celulares inteligentes.
2020-06-01 Se añade la documentación condensada (doc).
    Se añade el subdirectorio doc con la documentación condensada del circuito esquemático e impreso .
2020-06-01 Se unifica la dependencia en IRProxy.lib
    Se adapta el esquemático para eliminar los archivos *rescue y *cache, en este punto las partes incluidas en el solo dependen de IRProxy.lib
    [IRProxy.sch]
